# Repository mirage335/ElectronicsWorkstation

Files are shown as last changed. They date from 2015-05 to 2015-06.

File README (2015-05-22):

Copyright (C) 2015 mirage335
See the end of the file for license conditions.
See license.txt for ElectronicsWorkstation license conditions.

mirage335-site.dyndns.org

Specialized desk for precision electronics and micro-mechanical work. Large, 8' x 3' work surface, equipment shelf, and storage shelf. Drawers and sliding trays are also supported.

_Construction_
Equipment shelf height should provide adequate clearance for a large widescreen computer monitor, while being low enough to support several feet of equipment within reach while sitting. Ideally, soldering irons, oscilloscopes, power supplies, and similar equipment are all kept on the equipment shelf, leaving the work surface absolutely clean at all times. By default, 19" clearance is provided, fine adjustment is left to the user.

Bright lighting is essential for precision work. At least twelve ~40W (~2400 lumen) daylight compact flourescent light bulbs are recommended.

Consider ading reinforcement 2x4 segments between the worksufrace and floor, as shown in the photo. Also be sure to use plenty of wood glue and appropriately sized, well placed, coated deck screws. Order of operations is also important - some segments may need to be joined interally.

_Equipment_
Following equipment is recommended.

Microscope - AmScope SM-1BS, SM-1BN, SE304-PX, or SE104-P. Strongly recommend SM-1BS or SM-1BN. Be sure to mount protective glass over any microscope objectives while soldering to prevent damage.

Calipers - http://www.harborfreight.com/6-in-digital-caliper-with-sae-and-metric-fractional-readings-68304.html

Oscilloscope - Isolated (ie. battery powered) digital scopes with Vmax, Vavg, Vmin, Vrms, and frequency statistics preferred. DSO Nano recommended. - http://www.seeedstudio.com/depot/DSO-Nano-v3-p-1358.html
Bench Scope - Occasionally more channels and bandwidth is helpful, particularly if an envelope detector is not readily available. Consider an analog XY capable scope to go with the digital scope.
Function Generator - Should be capable of sine, triangle, and square waveform output at >1MHz.
LCR Tweezers - http://www.smarttweezers.us/

Tweezers - EROP7SA available from mouser.

Soldering Iron - WSM1/TWSM1/WSM1C, WD1000M, WX1011 (must use WMRP/WXMP soldering pencil) - http://www.amazon.com/Weller-WSM1-Compact-Digital-Soldering/dp/B00466IF60
Solering Iron Tips - RT1, RT3, available from Mouser.
Hot-Air Station - http://www.amazon.com/WEP-858D-Soldering-Station-Suitable/dp/B0055B6NGE
Solder Sucker - http://www.amazon.com/Parts-Express-Solder-Sucker--desoldering/dp/B0002KRAAG

Mr Coffee Hot Plate - Pre-warms PCBs to ~135degC, reducing risk of damage during hot-air soldering - http://www.amazon.com/Mr-Coffee-MWBLK-Mug-Warmer/dp/B000CO89T8

_Supplies_
Following supplies are recommended.

Solder - http://www.amazon.com/Amico-0-3mm-Rosin-Solder-Soldering/dp/B008DEYEAW
Solder Paste - CAUTION Highly Toxic! Wash hands thoroughly! - http://www.amazon.com/Kester-EP256-Solder-Syringe-Dispenser/dp/B006UTCYM2
Solder Wick - http://www.amazon.com/Aven-17542-Desoldering-2-5mm-Length/dp/B003E48ERU

Wrapping Wire - http://www.amazon.com/Amico-B-30-1000-Plated-Copper-Wrepping/dp/B008AGUDEY

Double Sided Tape - http://www.amazon.com/Scotch-Permanent-Double-Inches-3-Pack/dp/B0035LXTYU

_Random_
Random accessories may be added to the desk as follows.

Tray - Consider ading a 18"x24" sliding tray to the right side of the desk, as a convenient place for laptops, keyboards, mice, etc.
Monitor - Consider mounting a widescreen monitor with a 2x4 across the back.

__Credit__
http://www.hacdc.org/
http://www.amazon.com/?tag=hacdc-20
Thanks to HacDC for providing the resources to acquire prior experience needed to determine requirements for a workstation like this, and continuing to provide a friendly, well-equipped, colloborative environment. Please consider using HacDC's amazon affiliate link.

__Copyright__
This file is part of ElectronicsWorkstation.

ElectronicsWorkstation is free software: you can redistribute it and/or modify
it under the terms of the GNU General Public License as published by
the Free Software Foundation, either version 3 of the License, or
(at your option) any later version.

ElectronicsWorkstation is distributed in the hope that it will be useful,
but WITHOUT ANY WARRANTY; without even the implied warranty of
MERCHANTABILITY or FITNESS FOR A PARTICULAR PURPOSE.  See the
GNU General Public License for more details.

You should have received a copy of the GNU General Public License
along with ElectronicsWorkstation.  If not, see <http://www.gnu.org/licenses/>.

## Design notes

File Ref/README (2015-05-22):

Copyright (C) 2013 mirage335
See the end of the file for license conditions.
See license.txt for OpenBuildings license conditions.

mirage335-site.dyndns.org

Basic desk, optionally with acrylic surface and wheels.

Configurable to a variety of sizes.

For frame assembly, 3" deck screws, impact driver, and table saw recommended.

Plywood sheets may be adhered using drywall screws at 16" intervals and wood glue.

Acrylic surface may be attached with hot glue.

__Copyright__
This file is part of OpenBuildings.

OpenBuildings is free software: you can redistribute it and/or modify
it under the terms of the GNU General Public License as published by
the Free Software Foundation, either version 3 of the License, or
(at your option) any later version.

OpenBuildings is distributed in the hope that it will be useful,
but WITHOUT ANY WARRANTY; without even the implied warranty of
MERCHANTABILITY or FITNESS FOR A PARTICULAR PURPOSE.  See the
GNU General Public License for more details.

You should have received a copy of the GNU General Public License
along with OpenBuildings.  If not, see <http://www.gnu.org/licenses/>.

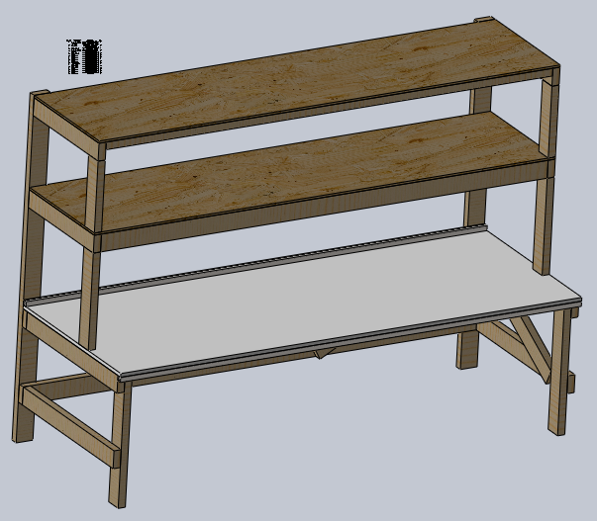
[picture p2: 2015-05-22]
Render.png

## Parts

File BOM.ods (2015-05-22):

ITEM NO. | PART NUMBER | DESCRIPTION | QTY. | 2x4?
1 | EngineeredWood- Tabletop | HomeDepot Model # 461877 Internet # 100070209 Store SKU # 461877 | 1 |  | 0
2 | SteelTube | MetalsDepot 1 X 1 X 11 GA (.120 wall) A513 Steel Structural Square Tube | 2 |  | 0
3 | 2x4_tabletop | HomeDepot Model 218458 SKU 218458 | 1 | 1 | 1
4 | EngineeredWood- Board | Model # 1702388 Internet # 202712040 Store SKU # 242898 - HALF | 2 |  | 0
5 | 2x4_tabletop | HomeDepot Model 218458 SKU 218458 - HALF | 2 | 0.5 | 1
6 | 2x4_frame | HomeDepot Model 218458 SKU 218458 | 2 | 1 | 2
7 | 2x4_frame | HomeDepot Model 218458 SKU 218458 - Half | 2 | 0.5 | 1
8 | 2x4_frame | HomeDepot Model 218458 SKU 218458 | 1 | 1 | 1
9 | 2x4_frame | HomeDepot Model 218458 SKU 218458 - Half | 2 | 0.5 | 1
10 | Plywood_7- 16X8X4_shelves | HomeDepot Model 386081 SKU 386081 - Half | 2 | 0.5 | 1
11 | 2x4_shelves | HomeDepot Model 218458 SKU 218458 | 4 | 1 | 4
12 | 2x4_shelves | HomeDepot Model 218458 SKU 218458 - Half | 4 | 0.5 | 2
13 | 2x4_frame | HomeDepot Model 218458 SKU 218458 - Half | 2 | 0.5 | 1
14 | 2x4_frame | HomeDepot Model 218458 SKU 218458 - Half | 2 | 0.5 | 1
15 | 2x4_frame | HomeDepot Model 218458 SKU 218458 - Half | 2 | 0.5 | 1
 |  |  |  |  | 17

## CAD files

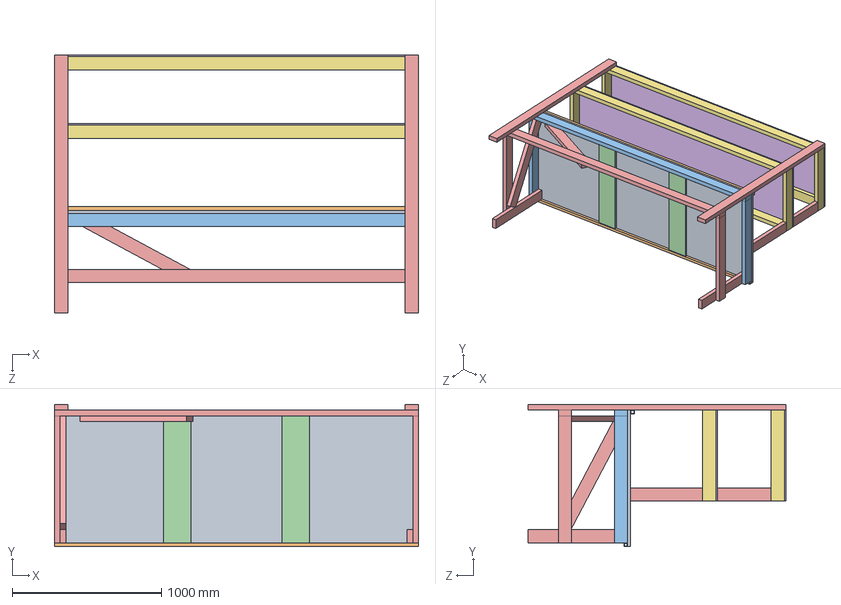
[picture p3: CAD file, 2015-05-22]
Frame/Frame.SLDASM
2438.4 x 952.5 x 1727.2 mm
EngineeredWood-Tabletop
SteelTube x 2
2x4_tabletop x 3
EngineeredWood-Board x 2
2x4_frame x 13
Plywood_7-16X8X4_shelves x 2
2x4_shelves x 8

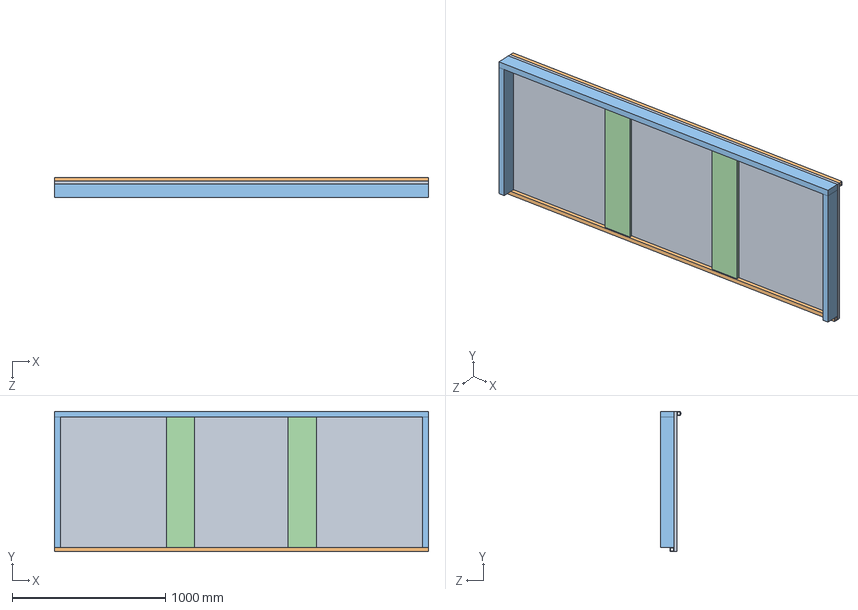
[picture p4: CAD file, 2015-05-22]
Tabletop/TableTop.SLDASM
2438.4 x 914.4 x 133.4 mm
EngineeredWood-Tabletop
SteelTube x 2
2x4_tabletop x 3
EngineeredWood-Board x 2

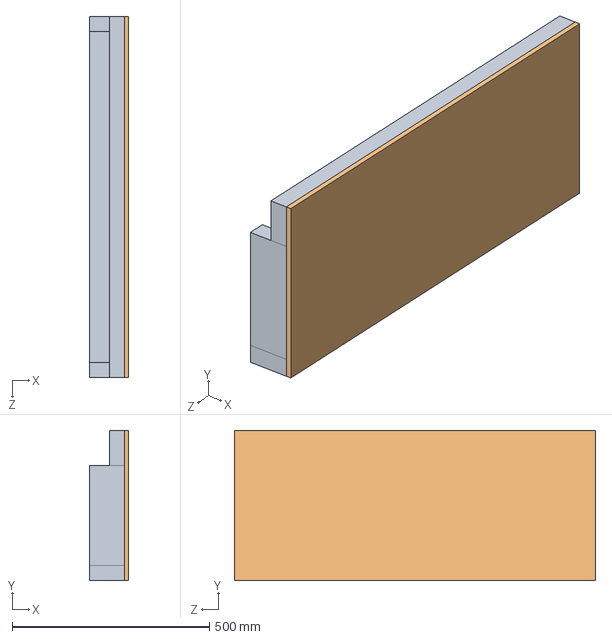
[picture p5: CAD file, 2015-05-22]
Ref/Materials/Drawer.SLDASM
100.0 x 381.0 x 914.4 mm
2x4_desk x 4
Plywood_7-16X8X4_desk

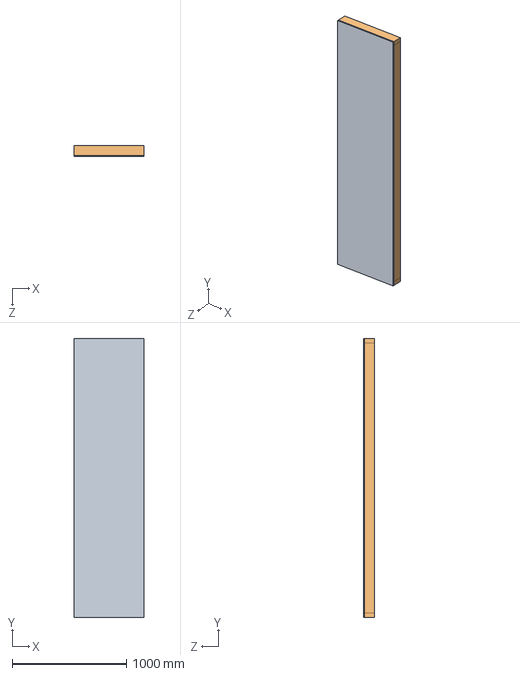
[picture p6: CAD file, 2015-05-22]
Shelves/Shelf.SLDASM
609.6 x 2438.4 x 100.0 mm
Plywood_7-16X8X4_shelves
2x4_shelves x 4

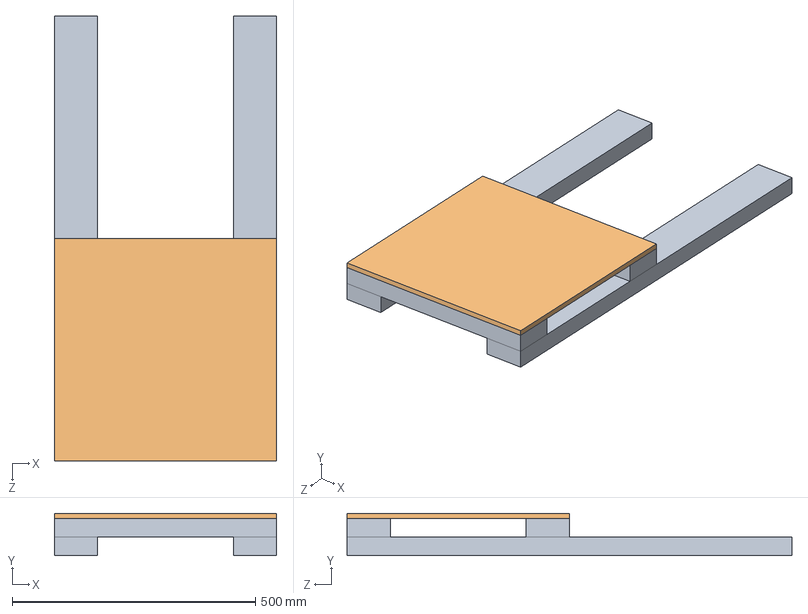
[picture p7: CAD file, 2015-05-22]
Ref/Materials/Tray.SLDASM
457.2 x 87.3 x 914.4 mm
2x4_desk x 4
Plywood_7-16X8X4_desk

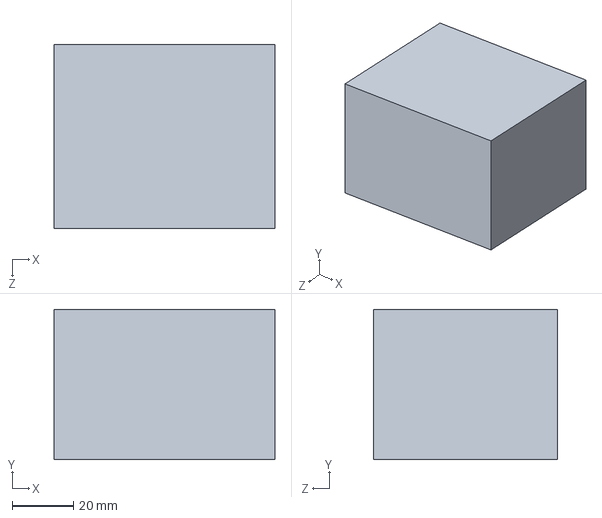
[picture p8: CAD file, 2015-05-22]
Ref/Materials/Casters_desk.SLDPRT
72.4 x 49.2 x 60.3 mm

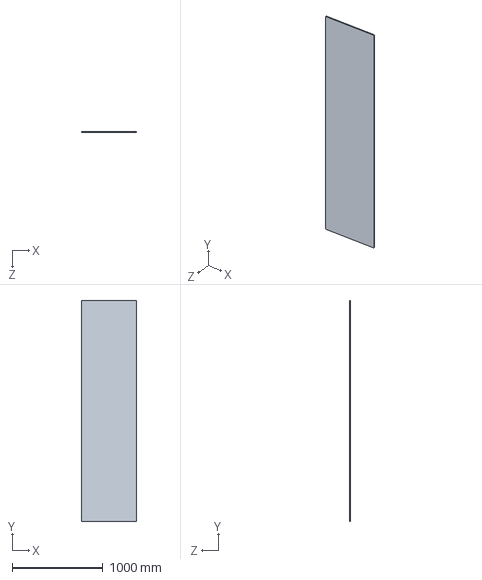
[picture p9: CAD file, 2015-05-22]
Shelves/Plywood_7-16X8X4_shelves.SLDPRT
609.6 x 2438.4 x 11.1 mm

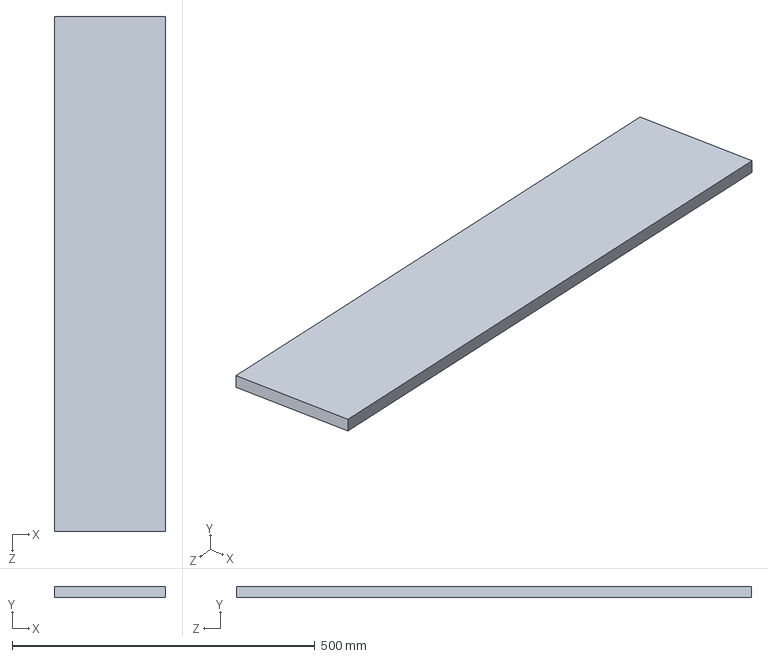
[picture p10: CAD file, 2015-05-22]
Tabletop/Materials/EngineeredWood-Board.SLDPRT
184.1 x 17.4 x 850.9 mm

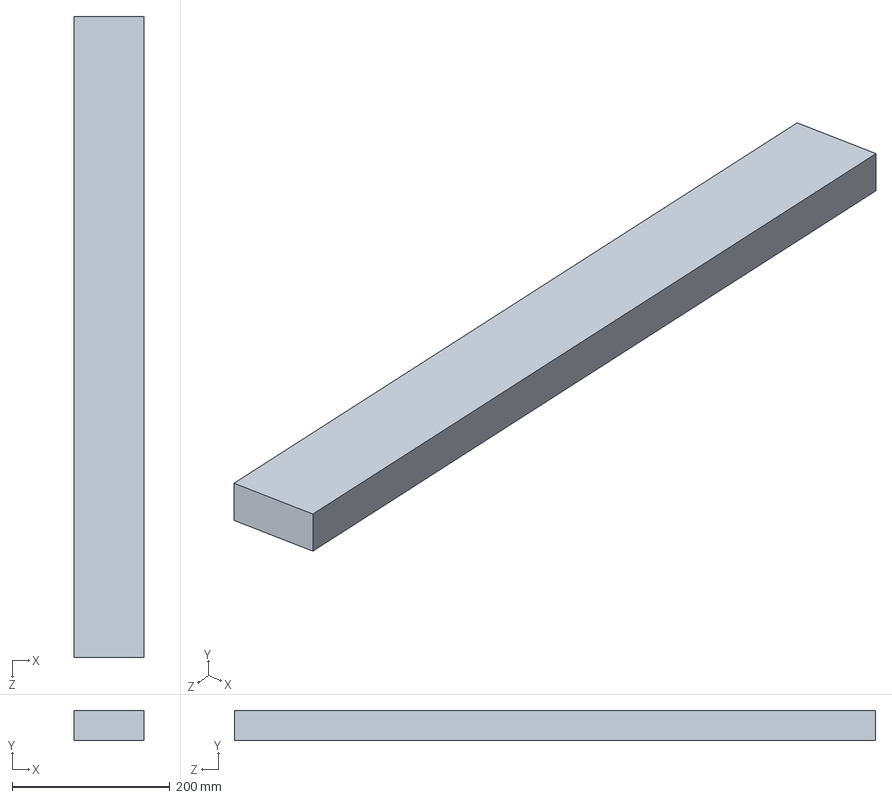
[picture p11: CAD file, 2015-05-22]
Frame/2x4_frame.SLDPRT
88.9 x 38.1 x 812.8 mm

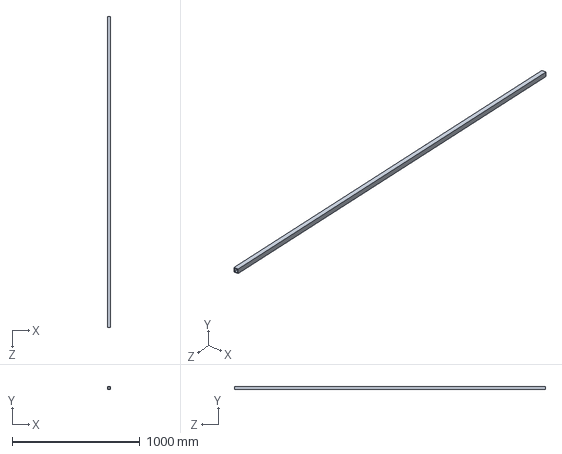
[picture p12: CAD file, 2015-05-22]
Tabletop/Materials/SteelTube.SLDPRT
25.4 x 25.4 x 2438.4 mm

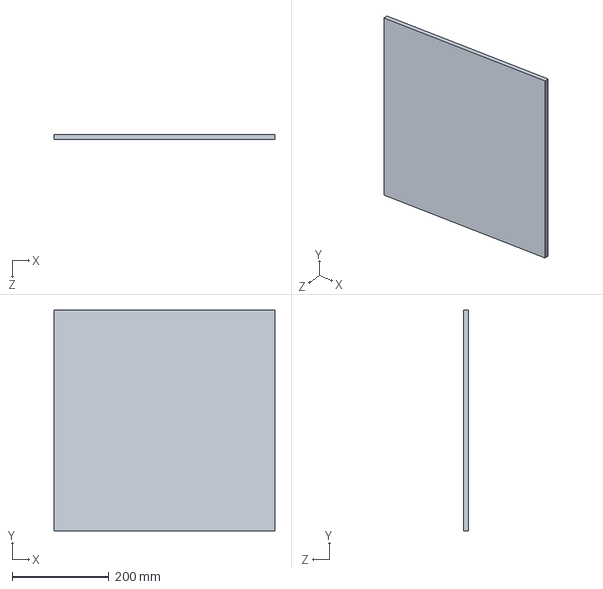
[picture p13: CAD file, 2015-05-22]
Ref/Materials/Plywood_7-16X8X4_desk.SLDPRT
457.2 x 457.2 x 11.1 mm

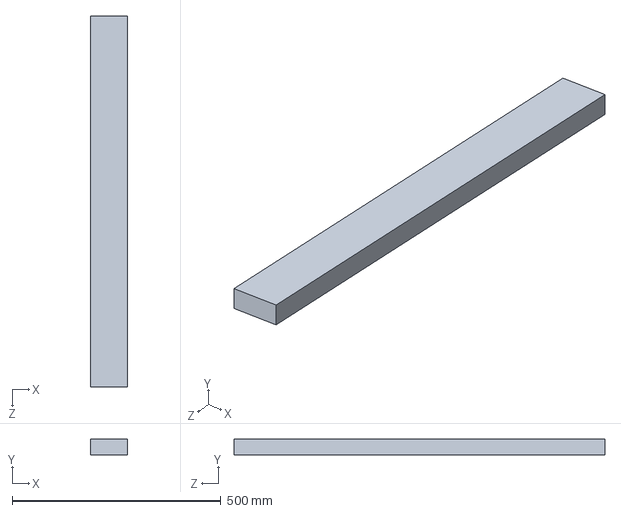
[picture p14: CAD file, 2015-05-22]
Shelves/2x4_shelves.SLDPRT
88.9 x 38.1 x 889.0 mm

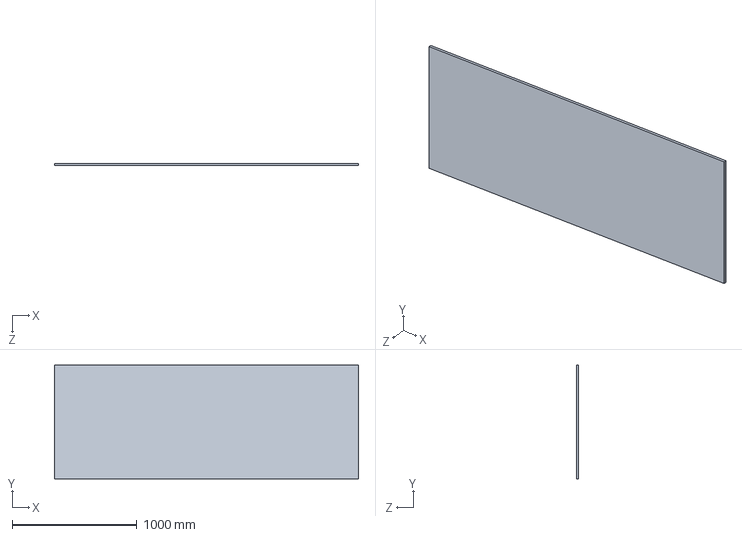
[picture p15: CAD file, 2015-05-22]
Tabletop/Materials/EngineeredWood-Tabletop.SLDPRT
2438.4 x 914.4 x 19.1 mm

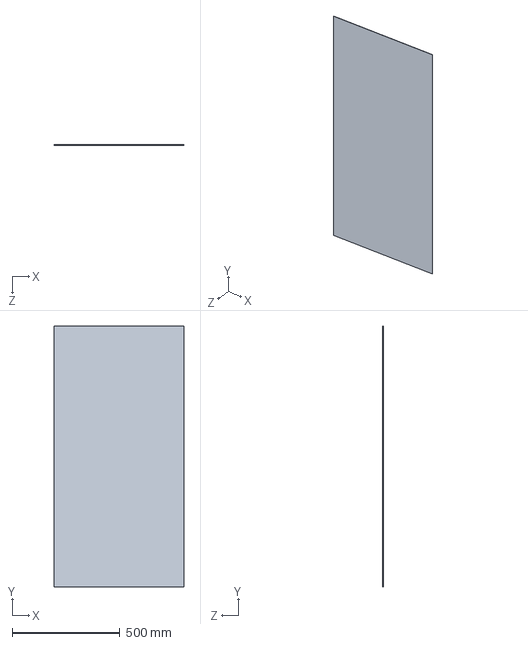
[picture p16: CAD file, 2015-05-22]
Ref/Materials/Acrylic_23.75X47.75_desk.SLDPRT
603.2 x 1212.8 x 1.65 mm

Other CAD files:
Shelves/TopShelf.SLDASM
Tabletop/Materials/2x4_tabletop.SLDPRT
Ref/Materials/2x4_desk.SLDPRT
